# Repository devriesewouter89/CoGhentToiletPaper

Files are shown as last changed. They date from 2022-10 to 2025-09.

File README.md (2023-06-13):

# CoGhentToiletPaper

## Project

	Bringin heritage closer to the people.
An installation interpreting images from [Collectie van de Gentenaar](https://www.collectie.gent/).

The installation places images on a unique timeline, where each image is semantically connected one way or the other.

This timeline is then printed on toilet paper.

_That's about as close as it gets to the people._

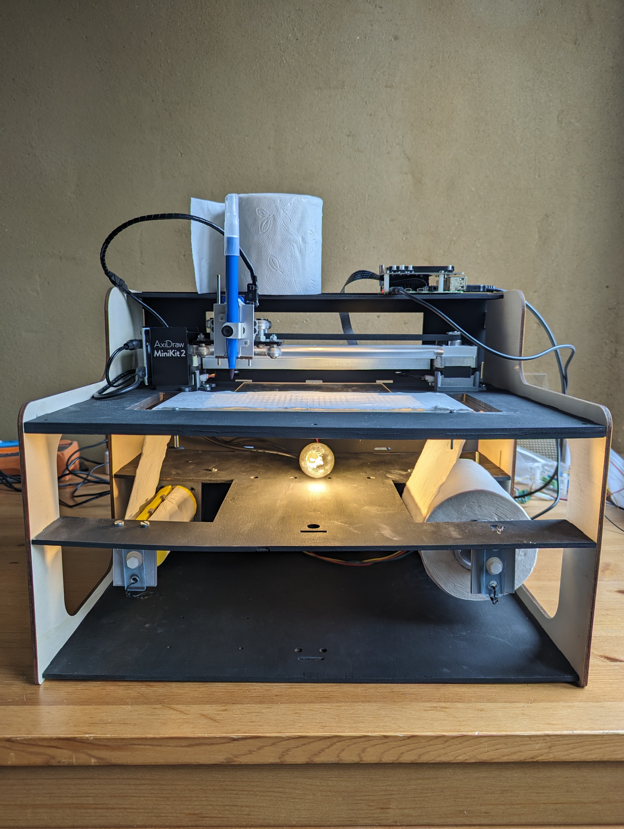
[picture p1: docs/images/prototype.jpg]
prototype


## installation

1. Start with a **64-bit** raspberry pi OS as Git lfs needs 64 bits

	tip: enable SSH & setup headless wifi via raspberry pi Imager and CTRL+SHIFT+X

2. Install GIT-lfs:
```bash
wget -c https://github.com/git-lfs/git-lfs/releases/download/v3.2.0/git-lfs-linux-arm64-v3.2.0.tar.gz -O - | tar -xvzf -
cd git-lfs-3.2.0
sudo ./install.sh
```

3. clone the repo with submodules and lfs:
```bash
git clone --recurse-submodules https://github.com/devriesewouter89/CoGhentToiletPaper/
cd CoGhentToiletPaper
git lfs pull
git submodule update --init --recursive
```

4. copy `.env.template` to `.env` and adapt to your needs.
5. install graphviz: `sudo apt install graphviz`
3. install poetry: `curl -sSL https://install.python-poetry.org | python3 -`
4. install all packages: `poetry install`
5. enable the environment: `poetry shell`

[//]: # TODO: adapt [prep_env.sh](./prep_env.sh)

[//]: # ()
[//]: # (**optional:** Want to run docker containers? install docker:)

[//]: # (```bash)

[//]: # (curl -fsSL https://get.docker.com -o get-docker.sh && sudo sh get-docker.sh)

[//]: # (sudo groupadd docker)

[//]: # (sudo usermod -aG docker ${USER})

[//]: # (sudo reboot)

[//]: # (```)

[//]: # ()
[//]: # ()
[//]: # ()
[//]: # ()
[//]: # (### image conversion)

[//]: # ()
[//]: # (multiple approaches:)

[//]: # (1. docker)

[//]: # (2. jupyter notebook)

[//]: # (3. directly via python scripts)

[//]: # ()
[//]: # ()
[//]: # (#### docker )

[//]: # ()
[//]: # (if CUDA cores available:)

[//]: # (```bash)

[//]: # (docker build -f Dockerfile.GPU -t imageconversion .)

[//]: # (```)

[//]: # ()
[//]: # (else )

[//]: # ()
[//]: # (```bash)

[//]: # (docker build -f Dockerfile.CPU -t imageconversion .)

[//]: # (```)

[//]: # ()
[//]: # (to run with the example folders: )

[//]: # (```bash)

[//]: # (docker run --name imgconv --mount type=bind,source="$&#40;pwd&#41;"/input,target=/coghent_input --mount type=bind,source="$&#40;pwd&#41;"/output/lineart,target=/workspace/coghent_vectors --mount type=bind,source="$&#40;pwd&#41;"/output/vectors,target=/workspace/coghent_lineart imageconversion)

[//]: # ()
[//]: # (```)

[//]: # ()
[//]: # (and then to start it:)

[//]: # (```bash)

[//]: # (docker start -a imgconv)

[//]: # (```)

## Nice to haves

### a web ui

perhaps in flutter? to check the state of the statemachine

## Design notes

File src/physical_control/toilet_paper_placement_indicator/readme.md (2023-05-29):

# template matching

    "hi chatgpt
    I need to align toilet paper based on the notches in the paper to two parallel lines. I want to use a camera and a machine learning model. Yet I don't know which kind of model to use, do you have a suggestion how to detect notches in paper?"
> "Hello! One approach you could take to detect the notches in the toilet paper using a camera and machine learning model is to use a computer vision technique called template matching. This involves creating a template image of a single notch and then using this template to search for instances of the notch in an input image. 
> 
> To create the template image, you can simply take a picture of a single notch using the camera. You will then need to pre-process the template image by converting it to grayscale and possibly applying some image filtering to improve the contrast and remove noise.
>
> To search for instances of the notch in the input image, you can use a technique called convolution to slide the template image over the input image and compare the template to each subregion of the input image. You can then use a metric to determine how closely the template matches the subregion, and if the match is above a certain threshold, you can consider the subregion to contain a notch.
> 
> There are many differing ways you could implement template matching, and the specific approach you take will depend on the specifics of your problem and the resources you have available. I hope this gives you a general idea of how you could approach this problem!"

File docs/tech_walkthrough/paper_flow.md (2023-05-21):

# paper flow

## steppers + camera

template matching
    => threshold + move away first before deciding to look again
need for light underneath paper to have enough contrast
work with region of interest: when does the paper leave or enter the region of interest?
    
needed to alter i2c address (by soldering a short circuit connection on pads)

## suction

fan beneath the paper
problem: turbulent air, not with prototype, yet with final version ==> no major issue

## angle 

I wanted a steep angle, for a certain visual appeal.
problem was that it tore the paper at the notches (it is intended for this of course...). So I had to make the angle less steep and make sure no sharp edges were in the path (smooth sanding to the rescue)

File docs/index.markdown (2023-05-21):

---
# Feel free to add content and custom Front Matter to this file.
# To modify the layout, see https://jekyllrb.com/docs/themes/#overriding-theme-defaults

layout: home
title: "Collectie van de Gentenaar: Gentse rol van het wc"
nav_order: 1
---

	Bringin heritage closer to the people.

An installation interpreting images from [Collectie van de Gentenaar](https://www.collectie.gent/){: .btn .btn-blue }.

The installation places images on a unique timeline, where each image is semantically connected one way or the other.

This timeline is then printed on toilet paper.

_That's about as close as it gets to the people._

prototype

## Oorsprong

*soon*

## Voortgang

*soon*

## walkthrough

Underneath [installation](./walkthrough/installation.html){: .btn } I've written an overview of the setup, from the
journey the toilet roll takes.

In [Software](./walkthrough/software.html){: .btn} there's a short writeup on all things software.

## Build it yourself

underneath [physical construct](https://github.com/devriesewouter89/CoGhentToiletPaper/tree/main/physical_construct) you
can find :

- the Fusion360 model (parameterized for plate thickness)
- lasercut files (plate thickness 3.8mm, create new lasercut files via the fusion360 model)
- the 3D print models

BOM:

- Raspberry Pi 4B
    - with power supply
    - with SC card
    - Raspberry pi Camera V3
- [Axidraw mini kit 2](https://shop.evilmadscientist.com/productsmenu/924)
- [Adafruit DC stepper hat](https://www.adafruit.com/product/4280)
- 2x Nema17 stepper
- bolts and nuts
- light bulb E14
- [light bulb fixation](https://www.gamma.be/nl/assortiment/profile-fitting-e14-zwart-2-st/p/B447774)
- [LCD Keypat hat](https://www.dfrobot.com/product-1884.html)
- large fan (to be defined)
- markers
    - I used children's markers, as they have a soft tip, useful for toilet paper and they don't dry out. Saves some
      headaches and running around.

# project origin

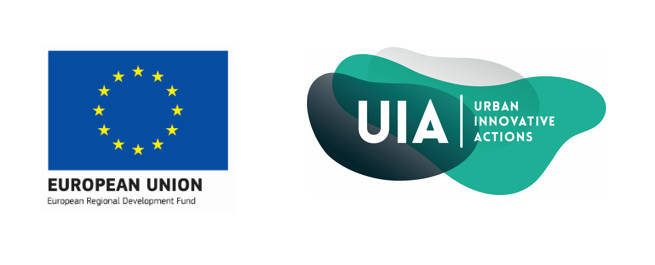
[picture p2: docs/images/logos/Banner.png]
UIA & europe

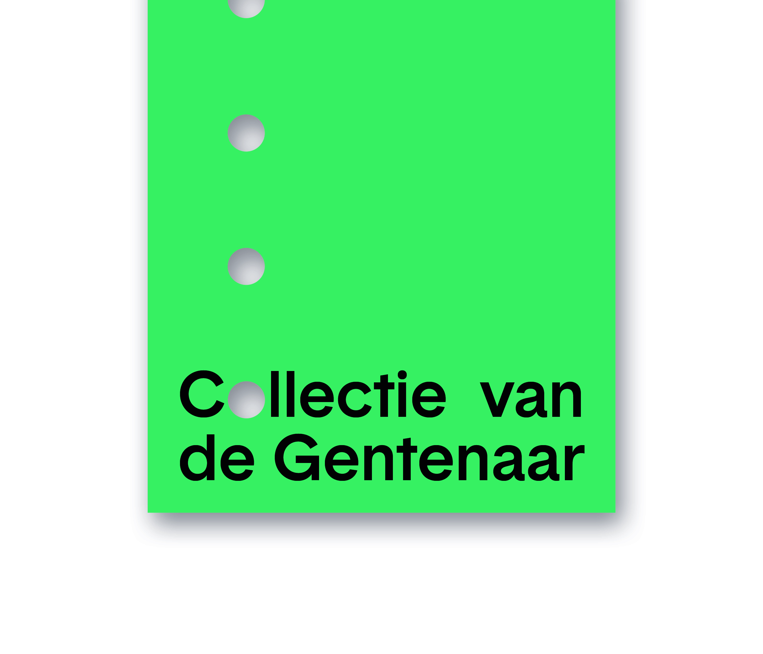
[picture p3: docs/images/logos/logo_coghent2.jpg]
coghent


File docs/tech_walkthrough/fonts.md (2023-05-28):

# fonts

going for the pen plotter with a wide soft tip, in combination with toilet paper, makes the ink flow too wide.

A couple of actions need to be taken into account:

## single line fonts

Most of the times we use outline fonts. Problem with plotters is that they draw the outlines, so they basically pass two times over the same region.
For a plotter it is best to have a single line font.

single vs outline fonts

[some more explanation](http://imajeenyus.com/computer/20150110_single_line_fonts/index.shtml)

## font size

## amount of text

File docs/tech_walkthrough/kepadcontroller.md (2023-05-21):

# keypad controller

manual intervention (to be programmed)
follow where in the flow we are

Needed to alter the i2c address of steppers as both were at same address.

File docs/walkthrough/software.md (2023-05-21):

---
# Feel free to add content and custom Front Matter to this file.
# To modify the layout, see https://jekyllrb.com/docs/themes/#overriding-theme-defaults

layout: page
title: "Software overview"
---

# Software overview

device level: Raspberry pi

language: Python

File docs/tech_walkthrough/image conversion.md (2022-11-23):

Target: prepare an image to be 2D plotted

Problem: images are mostly camera pictures, high res. Thus we need to convert it to line art to be able to plot it.

Found a cool repo: artline, If combined with some tracing programs, this was a good way to go to generate my lineart. Yet due to need of cuda to be able to run it, or need pytorch compiled for CPU. I had a rpi4 lying around, yet immediately getting pytorch (old version!) functioning gave problems with torchvision. I then started looking for some nvidia jetsons, yet apparantly covid chip shortage isn't over yet... So either I had to wait for some jetsons, or recompile pytorch, or go for another approach...

I found a different repo which did 

https://monokai.medium.com/how-to-wirelessly-plot-with-the-axidraw-f9e0a872138e

try with e.g. `saxi plot -s A5  --pen-down-height 2 --pen-up-height 25 --path-join-radius 1 0.svg`

PLOT with pencil what the borders are of A5, then measure the distance for the toilet paper ==> adapt svgs for this.

I've noticed the repo isn't up-to-date anymore and has some issues with polylines, therefore I've adapted my scripts to use only paths in svg.
Basically to avoid my lack of js and dependencies.

## Issues on the toilet paper front

1. paper moving
	1. test with multiple holed plates
	2. perhaps stronger suction? 
2. paper ripping with too many lines/ink
	1. lower the amount of lines close to each other?
3. placement of plotter vs paper 
	1. need to have a fixed position!
	2. have size fixed in 'saxi' library
4. pen vs pencil?
	1. test setup
5. which kind of toilet paper?

## platform

### 3D printed parts

#### fixation for toilet paper
- remove collar
- 2nd part: have fixed size and smaller stem coming out to center
- hole for stepper to big & not aligning nicely
- have at the beginning also some support for rolling?
#### fixation for roll rollers
2x https://www.thingiverse.com/thing:18019
or 2x https://www.thingiverse.com/thing:990946

#### fixation for axi draw
https://www.thingiverse.com/thing:669325 ==> adapt
1x with extraneous holes for screwing
1x half this design, with extraneous holes

#### connection for suction? 
kruimeldief

### platform
#### fixations for rollers & axi draw
- next to each other
- have not holes, but lines, to be able to align the axi draw & rollers slightly
#### colored line
have a not so comon colour to detect?
Or better black, but have image clear of other black things
#### suction panels
3 layer:
1. top layer: multiple hole configurations
2. middle layer: open surface to spread oxygen
3. bottom layer: access for suction pipe
glue middle and bottom
engrave or route the top and middle one to remove some material. in there we place some rubber or let dry some tec7 (separately) to remove air gaps
#### fixation for camera

#### placement of components:
- axidraw **above** the platform
- rollers **beneath** the platform
- camera **above** the platform
raise the platform approx 15cm, keep it tight not to have wiggle when printing

ME311549

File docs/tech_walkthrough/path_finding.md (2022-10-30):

Idee was startpunt te kiezen, sprong in de tijd maken en een zekere rang behouden. In die range kijken of er matches zijn.

Probleem 1: datums in de stream stonden niet mooi en met vreemde karakters ==> dit opkuisen
```python
def convert_column_first_year_via_regex(self):  
    """  
    convert_column_first_year_via_regex is a function that formats the "converted_creation_date" column in the pd dataframe to something readable    
    """    
    res = self.df[self.time_col].str.extract(r"([\d+]{4})").squeeze()  
    self.df.insert(10, self.clean_time_col, pd.to_numeric(res), True)
```

Eerste naieve testcase: ervan uitgaan dat er voldoende data is en kijken of ik, met voldoende tussenstappen (= # wc rol velletjes) voldoende afbeeldingen vind op x afstand en met een link tussen elkaar.

- Hoe de link zoeken? Lemmatization vs stemming van geselecteerde kolommen

%%todo: zet tekening van voorbeeld erbij (print statement)%%
x afstand: eerst op basis van tijd. Wat bleek: data niet uniform genoeg verspreid en tijd lijkt moeilijke metric.
Oplossing: laat tijd los! sorteren van alle entries op basis van tijd, maar dan gewoon sprong maken in de lijst met iedere keer een specifieke afstand en range. Dit komt ongeveer overeen met rekening te houden met de tijdsdistributie en toch te denken in tijd, maar veel gemakkelijker te implementeren.

van

```python
def find_indices_in_time_range(self, origin_year: int, time_distance: int, time_spread: int) -> (bool, list[int]):  
    new_origin = origin_year + time_distance  
    new_time_range = [new_origin - time_spread,  
                      new_origin + time_spread]  
    bool_array = self.df.index[  
        (new_time_range[0] <= self.df[self.clean_time_col]) & (self.df[self.clean_time_col] <= new_time_range[1])]  
    if len(bool_array) > 0:  
        res = bool_array.values.tolist()  
        res_bool = True  
    else:  
        res = None  
        res_bool = False  
    return res_bool, res
```
waar we in tijdstappen dachten naar:
```python
def 
```

Nu hebben we een forward motion die rekening houdt met de distributie ifv de tijd, om een path te vinden moeten we een boomstructuur aanmaken, want het is niet gezegd dat we altijd connecties gaan vinden en af en toe moeten we een tak verlaten en een andere tak uitproberen om tot op het einde te geraken! ==> backward motion

Afbeeldingen: de link downloaden: blijkt bij relatief wat afbeeldingen krijg ik geen afbeelding?

```python 
def get_image_uri(self, img_id) -> str:  
    iiif_manifest = "https://api.collectie.gent/iiif/presentation/v2/manifest/{}:{}".format(self.institute, img_id)  
    try:  
        response = urlopen(iiif_manifest)  
    except ValueError:  
        print('no image found')  
    except HTTPError:  
        print('no image found')  
    else:  
        data_json = json.loads(response.read())  
        image_uri = data_json["sequences"][0]['canvases'][0]["images"][0]["resource"]["@id"]  
        return image_uri
def get_image_list_from_tree(self):  
    # we pick the rows from our dataframe which were chose  
    index_list = self.df_tree[self.df_tree["chosen"] == True].index  
    # based on these indexes we pick the data from within our original dataframe  
    df_list = self.df.iloc[self.df.index.isin(index_list)]  
    # we make a list of the objectnumbers, as they are needed to retrieve images  
    object_id_list = df_list["objectnumber"].values  
    img_list = list(map(lambda x: self.get_image_uri(x), object_id_list))  
    for i in img_list:  
        print(i)  
    print(len(img_list))
```
Got me on a random occasion only 12 out of 50 results. Not good...

Plan van aanpak: bij het bouwen van de tree reeds rekening houden met het resultaat van get_image_uri!

Nu wordt alles wel heel traag (serieel alle uri's opvragen), dus gaan we threaded werken!

Van 
```python
def find_overlap_in_series(self, origin, indexes) -> (bool, list[dict]):  
    """  
    @rtype: object  
    @param origin:    @param indexes:    """  
    print("origin:")  
    print(self.df_row(origin))  
    res = list()  
    res_found = False  
  
    for i in indexes:  
        if i == origin:  
            continue  
        # print(self.df_row(i))  
        overlap_found, overlap_list, img_uri = self.find_overlap(origin, i)  
        if overlap_found:  
            print(Fore.GREEN)  
            print(overlap_list)  
            res.append({"index": i, "res": overlap_list, "img_uri": img_uri})  
            res_found = True  
        else:  
            # print(Fore.RED + "nothing found")  
            continue  
        print(Style.RESET_ALL)  
    return res_found, res
```

Naar threaded:

```python

def find_overlap_threaded_in_series(self, origin, indexes) -> (bool, list[dict], list[str]):  
    """  
    TODO not satisfied with this, not functionally written!  
    @rtype: object  
    @param origin: the index in the original dataframe for which we're looking for childs in <indexes> with a textual overlap    @param indexes: the indexes of possible children    """  
    print("origin:")  
    print(self.df_row(origin))  
    res = list()  
    res_found = False  
  
    # we'll multithread the find_overlap function to speed things up  
    que = Queue()  
    threads_list = list()  
    for i in indexes:  
        if i == origin:  
            continue  
        t = Thread(target=lambda q, arg1, arg2: q.put(self.find_overlap(arg1, arg2)), args=(que, origin, i))  
        t.start()  
        threads_list.append(t)  
    for t in threads_list:  
        t.join()  
    while not que.empty():  
        overlap_found, overlap_list, img_uri, index = que.get()  
        if overlap_found:  
            print(Fore.GREEN)  
            print(overlap_list)  
            res.append({"index": index, "res": overlap_list, "img_uri": img_uri})  
            res_found = True  
        else:  
            # print(Fore.RED + "nothing found")  
            continue  
        print(Style.RESET_ALL)  
    return res_found, res
```

Now, my algorithm is basically:
- You have a startnode
- Find all indices we want to evaluate
- Find all childs based on the indices which have a textual overlap with our startnode
- choose one of them as a new startnode
	- If no child nodes are to be found, switch the new startnode

As this takes a long time, perhaps it's faster for future reference to NOT choose the new startnode, yet search childs with overlaps for all nested childs. This implicates:
- more memory usage
- small rewriting part (not choosing one branch + keeping track of the parent)
- if the database is renewed, entire process needs to be redone.

So I've rewritten my flow for easier reuse:
- instead of finding a unique path and only saving this path towards the end
- I build the entire tree structure
- and find a possible path afterwards
- This way making it possible to recuperate the builded tree structure.
As I only keep a link to the images, I don't have this huge memory bounty.

Now, after having some hassles rewriting the code in threads. It takes a **long** time to make the tree structure. That made me think that I check often for the same entry if there's an image present as they appear in different branches. Thus, I'll rewrite the code again to add the uri, if available, to the original dataframe. Then I don't need to have so many requests (which is the bottleneck, together with my sense of patience)

I now preprocess the data to first go through all images and find their URI, if there's none I don't keep them. 
My initial plan was to process all data into a tree, yet after running an entire night I came to next conclusion: it's becoming way to large and slow. I need 50 layers, by morning I had 9 (with 1000 threads in parallel, and a spread of 3):

- layer 1: 1 id to check @ 22:25:34
- layer 2: 5 ids to check
- layer 3: 30 ids to check
- layer 4: 150 ids to check
- layer 5: 738 ids to check
- layer 6: 3947
- layer 7: 19849
- layer 8: 94446
- layer 9: 444545  (400000 @ 08:35:35) ==> I'm not that patient!

each 1000 threads took approx 2 minutes at layer 9. Perhaps my dataframe is becoming too large to be efficient... At layer 8 it was about 20 seconds...

So I went for again a different approach:
- first check for each entry if there's an image present as well as a useful date. Other entries I drop.
	- Especially the image present gave a huge dropout:
		- for dmg: out of 9142 ids, we got next HTTP errors: {'403': 1245, '404': 6789, '502': 18}
		- in DMG there are some weird object ids: `/iiif/presentation/v2/manifest/dmg:DES. 1995.16_0-2` what's the space doing there? the object can't be found + throws an error 
		- for hva: `of 8574 ids, we got next HTTP errors: {'403': 9, '404': 6700, '502': 2}`

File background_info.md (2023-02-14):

[pen plotters](https://uunatek.com/top-5-best-axidraw-xy-plotter-pen-plotter-alternatives/)

[print on masking tape](https://hackaday.com/2022/05/09/all-the-sticky-labels-you-could-ever-need-no-drm-just-masking-tape/)

[evil mad scientist plotter](https://shop.evilmadscientist.com/)

[AI model art to line art](https://github.com/vijishmadhavan/ArtLine)

blob detection voor grote zwarte vlakken
contour blob behouden, opvullen ahv hatch

https://learnopencv.com/blob-detection-using-opencv-python-c/ ?
https://ezdxf.readthedocs.io/en/stable/tutorials/hatch.html ?

[potrace](https://pypi.org/project/pypotrace/) ==> of im2vec of deepSVG

[DIY pen plotter with automatic tool changer](https://www.youtube.com/watch?v=virDtVVt2Xo)

[diy plen plotter](https://www.youtube.com/watch?v=u26Wt8eY5zc)

[cheap chinese woodworking tools reviewed](https://www.hookedonwood.online/China-Tools/)

[docker+nvidia+vscode development](https://blog.roboflow.com/nvidia-docker-vscode-pytorch/)

[IIIF tricks](https://iiif.io/api/image/3.0/)
e.g. rescale images: https://github.com/CoGhent/random_image_viewer/blob/master/getimage/views.py line 45

To align toilet paper, should I be using segmentation masks?
https://blog.roboflow.com/how-to-create-segmentation-masks-with-roboflow/

# rpi camera mount

- https://www.thingiverse.com/thing:3079477 ?

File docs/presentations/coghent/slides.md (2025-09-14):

---
theme: apple-basic
class: text-center
highlighter: shiki
lineNumbers: false
info: |
  Presentation slides for Collectie van de Gentenaar

drawings:
  persist: false
layout: intro
title: Gentse Rol van het WC
---

# De Gentse rol van het WC

Wouter Devriese

---
transition: fade-out
---

# Oorsprong

1. collectie - LDES:
    1. weerspiegeling fysieke collectie
    2. semantisch verrijkt
    3. definitieve inhoud? (updates - toevoegingen)

<v-click>

2. hoe kan men naar de collectie kijken?
    1. minder gecureerd
    2. individu kiest zelf pad doorheen de collectie
    3. persoonlijk: muziek leren kennen
        1. voor gekauwde playlists 
        2. zelf verbanden zoeken

</v-click>

<!--
het punt van de collectie is dat het dus op een LDES stream staat, wat ik daar persoonlijk uit interessant vond was het punt dat het naast de weerspiegeling van de fysieke collecties, ook semantisch verrijkt is, en dat objecten updates kunnen krijgen, of dat objecten toegevoegd worden. De collectie krijgt zo een dynamisch kantje

-->

---
layout: default
transition: fade-out

---

# Brainstorm 

Algemene vragen:

- tijdslijn?
- fysiek aandenken?
- collectie tot bij burger?

...

---
layout: image-right
image: https://i.guim.co.uk/img/media/e1492f95308c7f3b1c1e13ba51f57e02fd4021c5/0_236_7087_4254/master/7087.jpg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
---

# Brainstorm 

Algemene vragen:

- tijdslijn?
- fysiek aandenken?
- collectie tot bij burger?

...

WC-papier 

---
layout: image-right
image: ./images/prototype_2.jpg
---

# Installatie

- die telkens nieuwe paden doorheen de collectie zoekt
- deze print op een WC-rol
- zo unieke wc-rollen creerend

---
layout: 3-images
imageLeft: ./images/process/tree.png
imageTopRight: ./images/process/in_between.svg
imageBottomRight: './images/process/0.jpg'
---
---
layout: image-right
image: ./images/process/0.jpg
---

# download image

---
layout: image-right
image: ./images/process/lineart.png
layout: image-left
image: ./images/process/tree.png
---

# pad

"Deze **stoel** heeft een hoge rechte rugleuning die wordt benadrukt door het snijwerk van de kapregel. 
De rechte achterpoten van de **stoel** lopen zonder onderbreking over in de stijlen van de rugleuning. 
Deze **stoel** werd geconstrueerd in de 19de eeuw met <u>vermoedelijk</u> <...>"

"Deze pronkzetel met vernieuwde <...> 
Achteraan steunt de **stoel** op sabelpoten ('à l'étrusque'). <...> werd hij <u>vermoedelijk</u> uitgevoerd in het midden van de 19de eeuw. 
Vergelijkbare **stoel**en zijn te vinden in de collecties van het Bayerisches Nationalmuseum in München en Musée des Arts Décoratifs in Parijs."

*'stoel', 'eeuw', 'vermoedelijk', '19de'*

---
layout: default

---


---

# convert to lineart
---
layout: image-right
image: ./images/process/0.svg
---

# convert to lineart
layout: default
image: 
---

# conversion



<!--

---
layout: image-right
image: ./images/coghent_fest.MP4
---

# Doel

*Erfgoed dichter bij de burger brengen*

nut van

<v-clicks>

- WC-rol als functioneel object 
    - niet noemenswaardig
- WC-rol als esthethisch object 
    - niet noemenswaardig
- WC rol & installatie als conversation starter

</v-clicks>
 -->
---
layout: image-right
image: ./images/fusion.jpg
---

# bouwen

<v-click>

- LDES als nieuwe technologie
- code
- mechanisch ontwerp:
    - fast prototyping (zaag + vijs + ducttape)
    - 3D print
    - lasercut
- open-source reproduceerbaar 
- WC-papier als medium = horror
</v-click>

---
layout: 3-images
imageLeft: images/paper/lots.jpg
imageTopRight: images/paper/notches.png
imageBottomRight: images/paper/too_much_ink.jpg
---

---
layout: default
transition: fade-out
---

# evolutie


---
layout: default
transition: fade-out

---

# evolutie

---
layout: default
transition: fade-out

---

# evolutie

---
layout: default
transition: fade-out

---

# evolutie

---
layout: default
transition: fade-out

---

# evolutie  
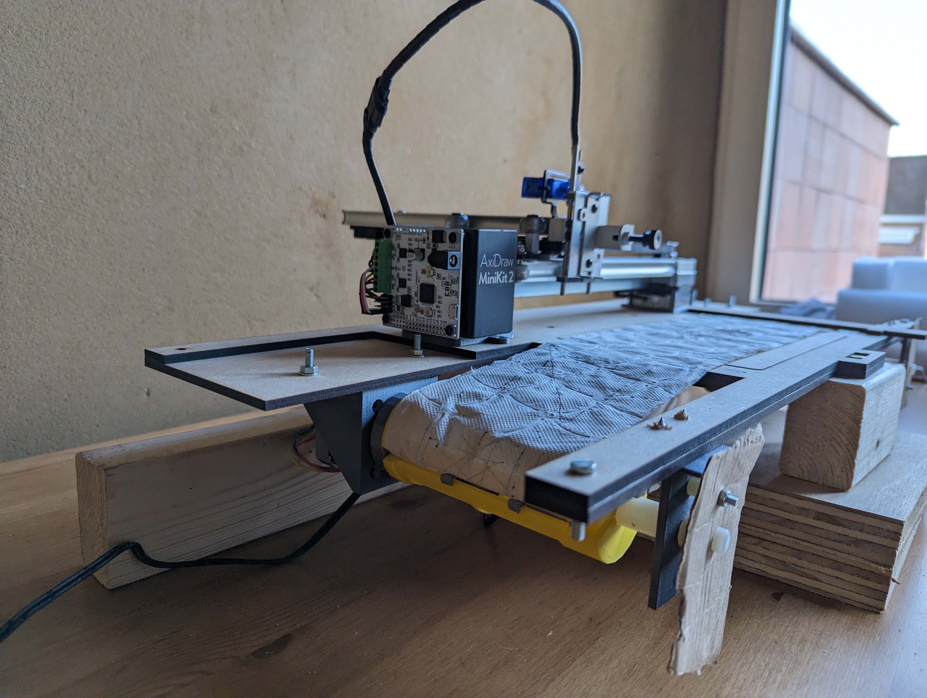
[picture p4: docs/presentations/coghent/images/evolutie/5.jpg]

---
layout: default
transition: fade-out

---

# evolutie

---
layout: default
transition: fade-out

---

# evolutie

---
layout: default
transition: fade-out

---

# evolutie

---
layout: default
transition: fade-out
---

# evolutie


---
layout: center
transition: fade-out
---

# "Final"
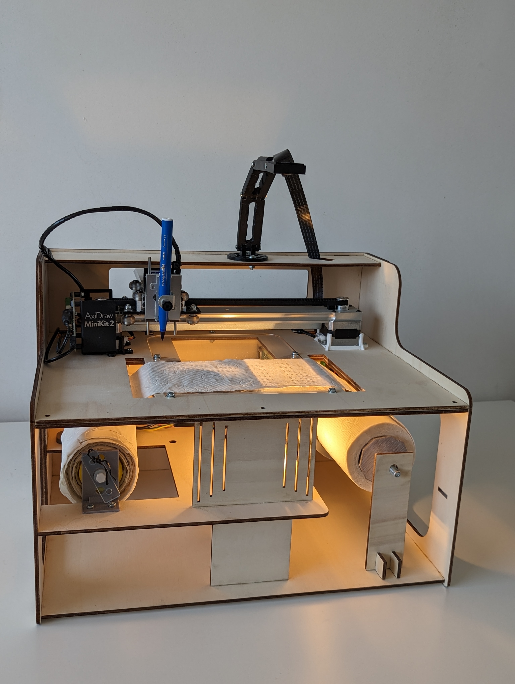
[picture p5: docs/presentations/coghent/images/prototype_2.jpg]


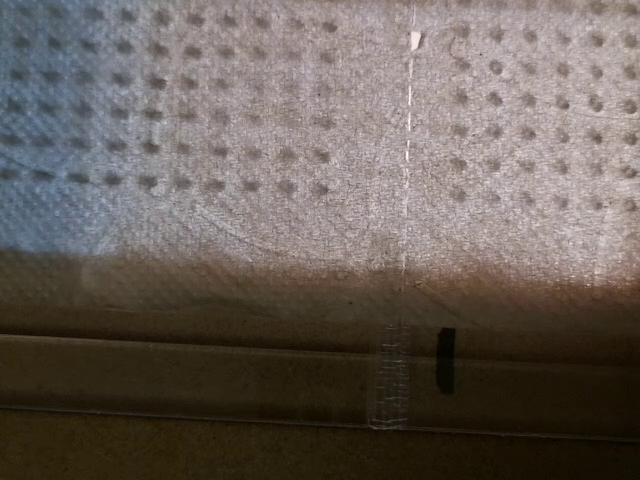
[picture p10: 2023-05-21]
docs/presentations/coghent/public/images/paper/notches.png

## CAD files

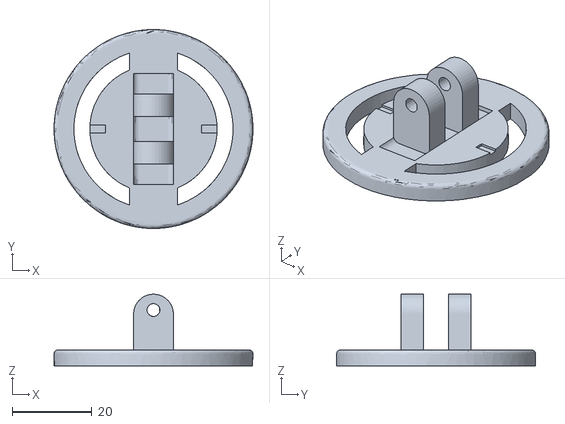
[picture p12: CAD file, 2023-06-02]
3DPrint/Camera/Camera_foot.stl
50.0 x 49.9 x 18.0

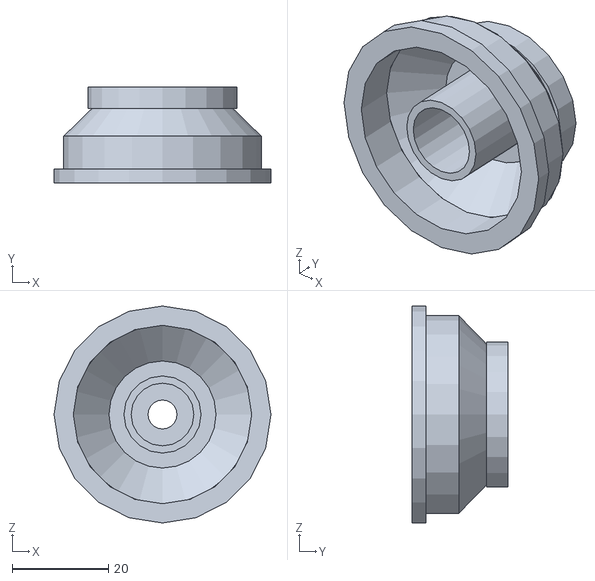
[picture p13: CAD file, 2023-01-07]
3DPrint/roll_fixation/paper_roll_side/other_side_toilet_fixation.stl
45.0 x 20.0 x 45.0

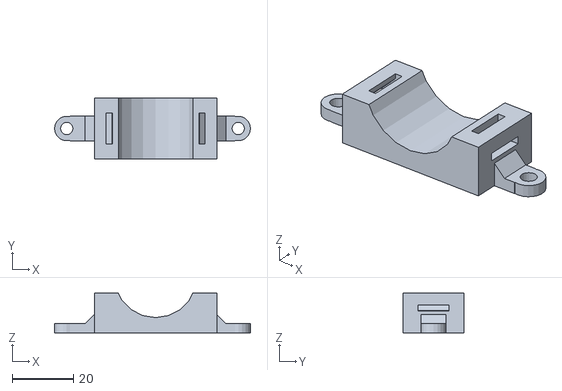
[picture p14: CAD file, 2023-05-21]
physical_construct/3DPrint/light_bulb_fixation.stl
64.0 x 20.0 x 13.0

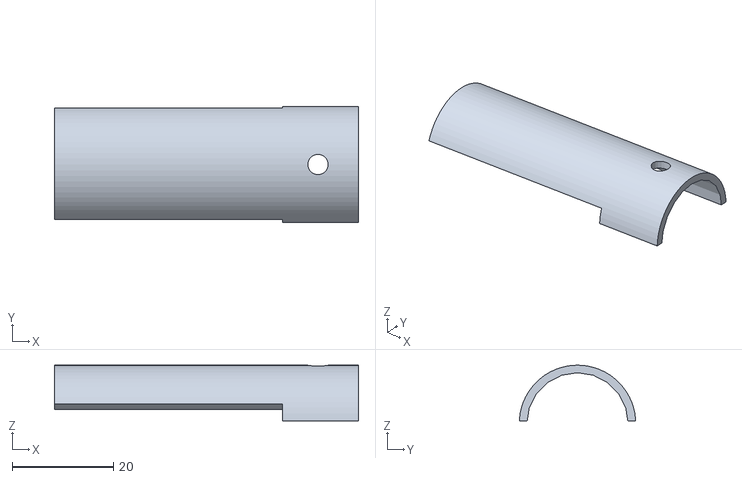
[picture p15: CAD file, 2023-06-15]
physical_construct/3DPrint/roll_fixation/grabber_side/v6_fix.stl
60.0 x 23.0 x 11.0

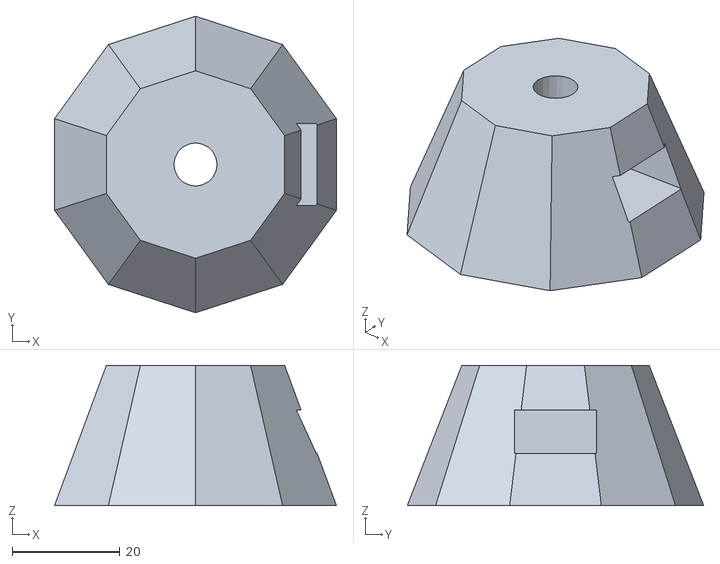
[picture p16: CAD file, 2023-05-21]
physical_construct/3DPrint/roll_fixation/paper_roll_side/roll_fixer.stl
52.3 x 55.0 x 26.0

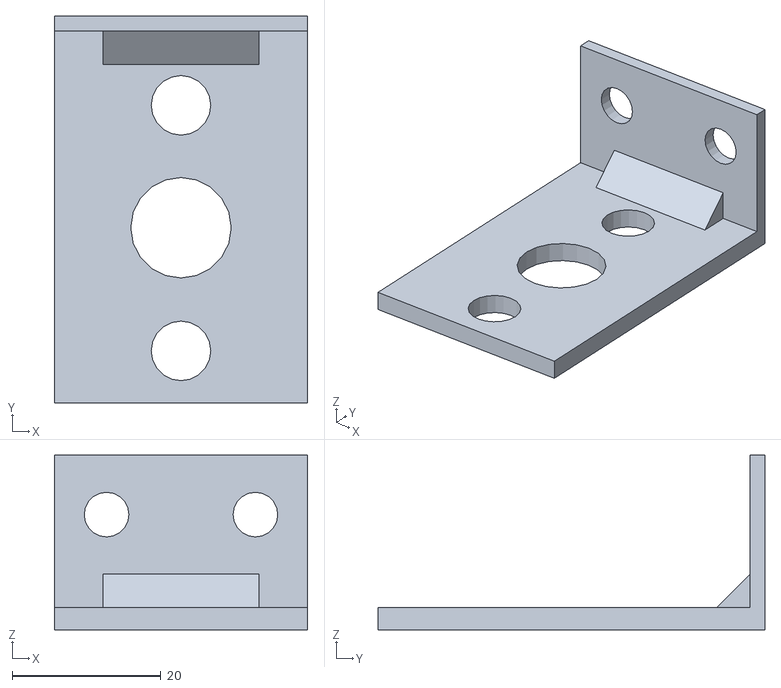
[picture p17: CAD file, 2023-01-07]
physical_construct/3DPrint/roll_fixation/toilet_roll_balancer.stl
34.0 x 52.0 x 23.5

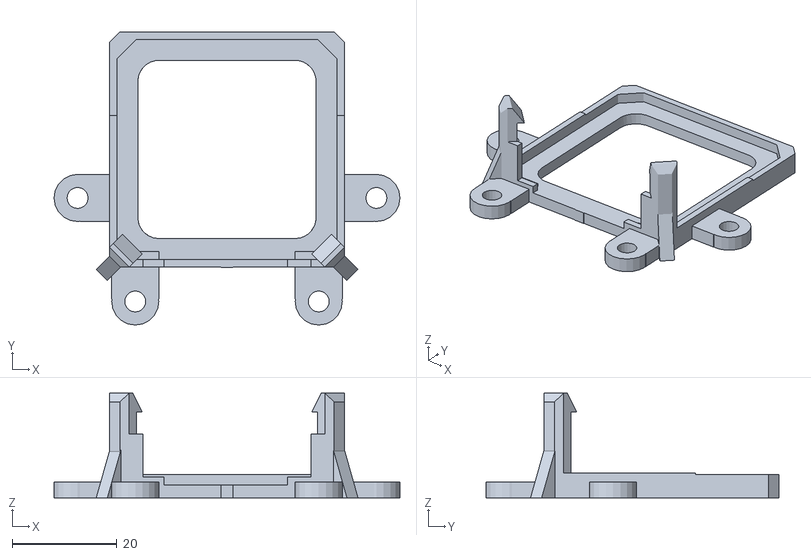
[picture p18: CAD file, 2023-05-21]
physical_construct/3DPrint/steppers/axi_draw_fixation/left_axi.stl
66.0 x 55.9 x 20.0

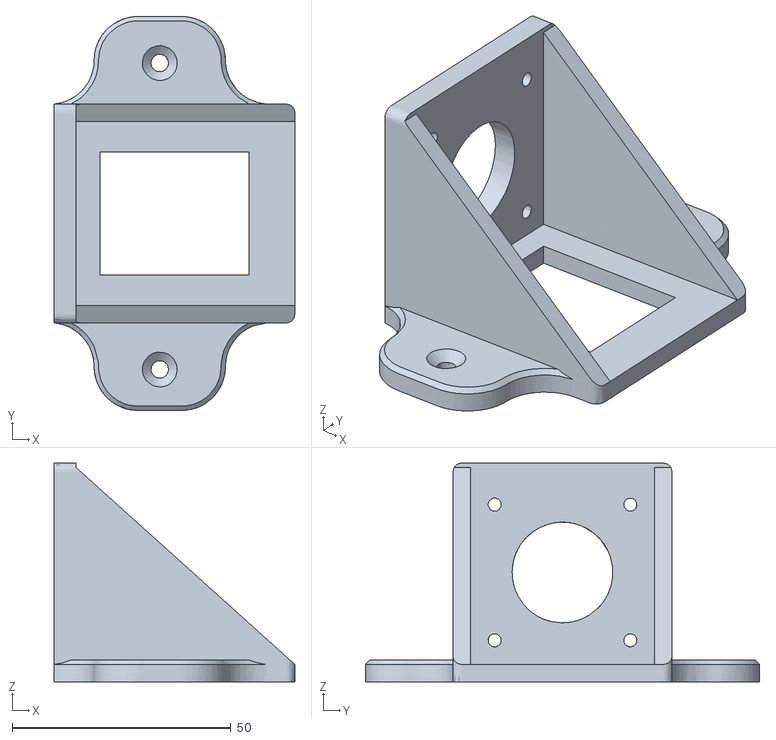
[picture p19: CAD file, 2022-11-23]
physical_construct/3DPrint/steppers/toilet_rollers/roller.stl
55.0 x 90.0 x 50.0

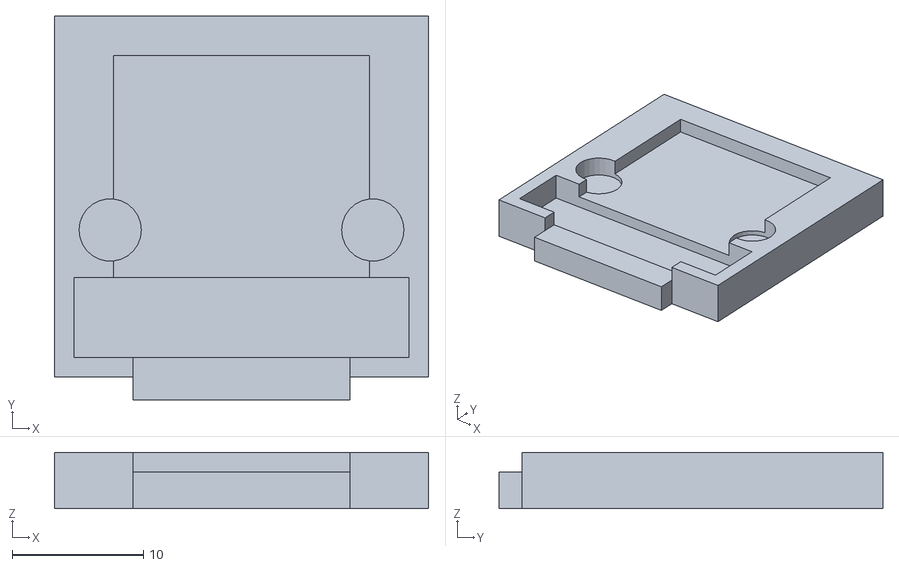
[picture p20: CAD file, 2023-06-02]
3DPrint/Camera/Camera_backplate.stl
28.5 x 29.2 x 4.30

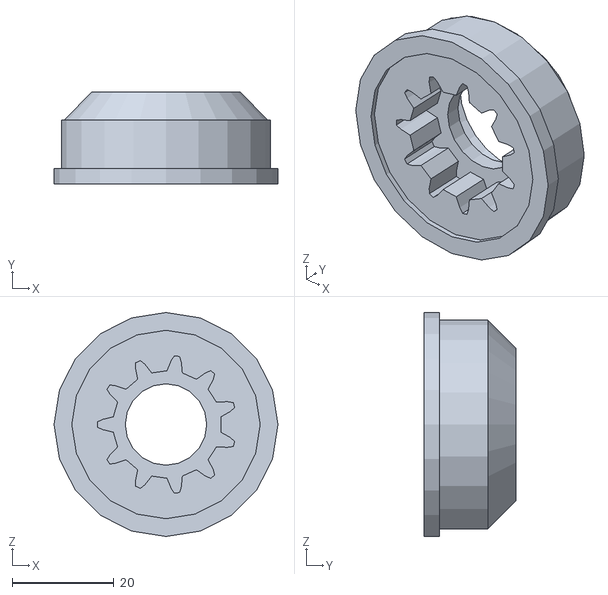
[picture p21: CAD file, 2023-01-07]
3DPrint/roll_fixation/paper_roll_side/nema17_toilet_fixation_1.stl
44.0 x 18.0 x 44.0

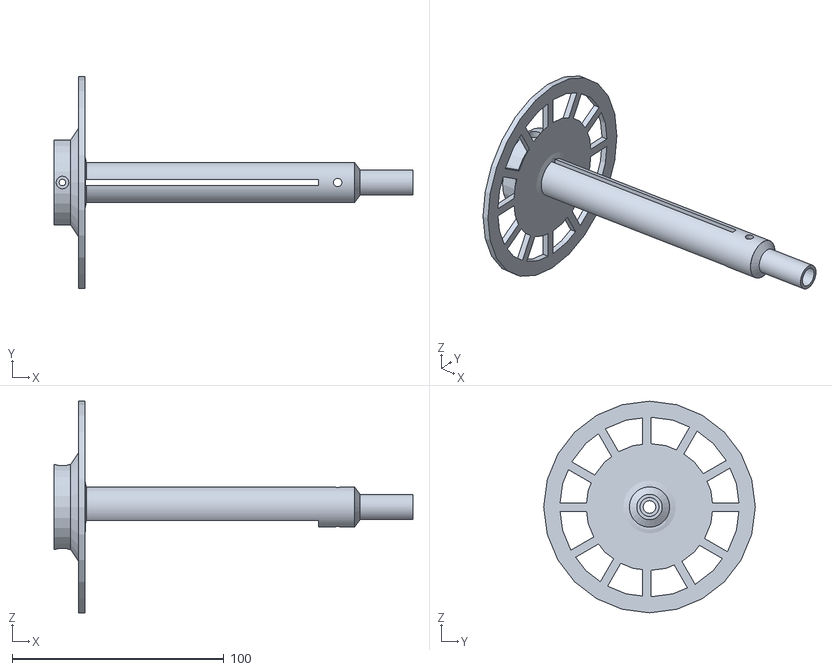
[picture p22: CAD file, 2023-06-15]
physical_construct/3DPrint/roll_fixation/grabber_side/v6.stl
169.6 x 100.0 x 100.0

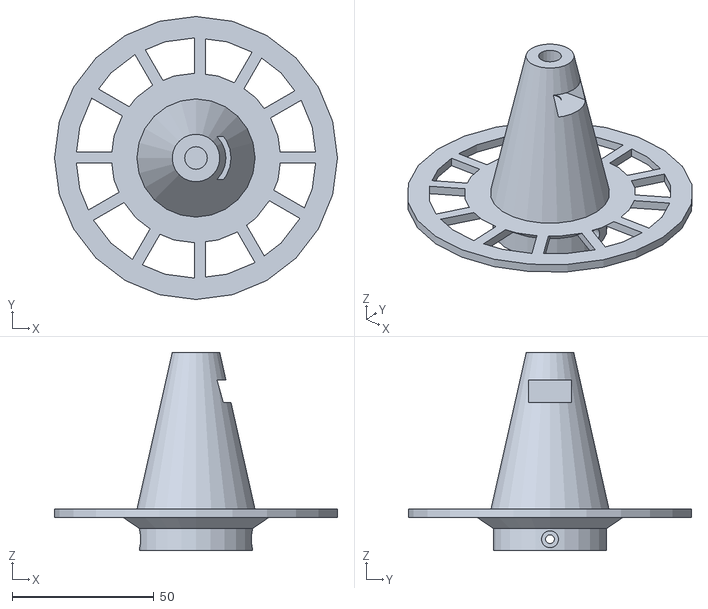
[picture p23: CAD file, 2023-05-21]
physical_construct/3DPrint/roll_fixation/paper_roll_side/roll_to_stepper.stl
100.0 x 100.0 x 70.0

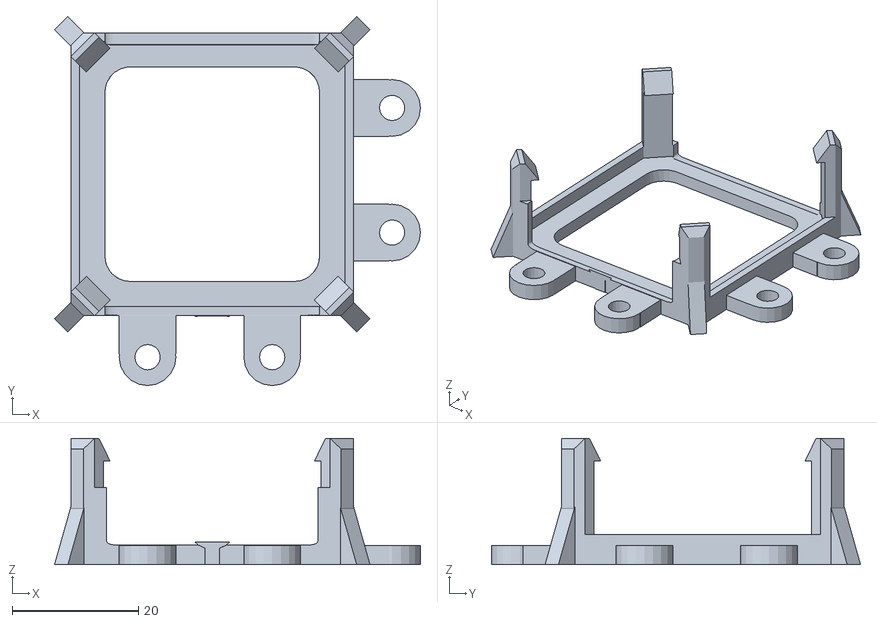
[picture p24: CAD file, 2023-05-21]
physical_construct/3DPrint/steppers/axi_draw_fixation/right_axi.stl
58.0 x 58.5 x 20.0

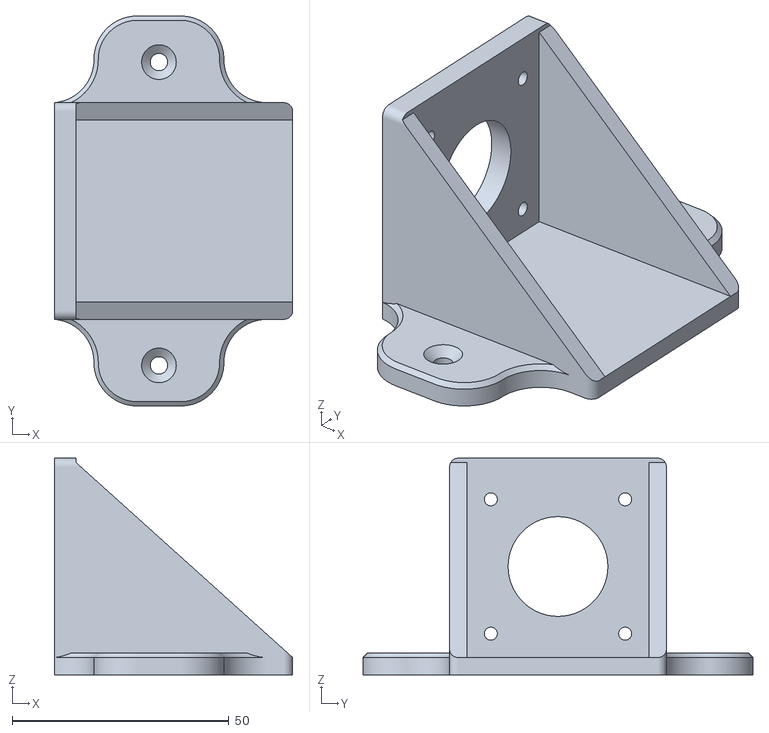
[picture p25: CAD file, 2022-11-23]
physical_construct/3DPrint/steppers/toilet_rollers/StepperMotorBracket.stl
55.0 x 90.0 x 50.0

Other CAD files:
3DPrint/Camera/Arm_3.stl
3DPrint/roll_fixation/paper_roll_side/nema17_toilet_fixation_2.stl
physical_construct/3DPrint/roll_fixation/grabber_side/toilet_grabber_insert_small.stl
3DPrint/Camera/Arm_1.stl
3DPrint/Camera/Arm_2.stl
3DPrint/Camera/Camera_frontplate.stl
physical_construct/3DPrint/roll_fixation/grabber_side/toilet_grabber.stl
physical_construct/3DPrint/roll_fixation/grabber_side/toilet_grabber_insert.stl
physical_construct/3DPrint/roll_fixation/paper_roll_side/OLD/nema17_toilet_fixation_2.stl

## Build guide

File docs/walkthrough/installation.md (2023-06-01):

---
# Feel free to add content and custom Front Matter to this file.
# To modify the layout, see https://jekyllrb.com/docs/themes/#overriding-theme-defaults

layout: page
title: "Installation Overview"
---

# Process

1. [getting the data and preparing it](#getting-the-data-and-preparing-it)
2. [insert paper roll](#insert-paper-roll)
3. [paper gets sucked down with the fan](#paper-gets-sucked-down-with-the-fan)
4. [two steppers to roll off the paper](#two-steppers-to-roll-off-the-paper)
5. [when to stop rolling? Camera + notches + light to the rescue](#when-to-stop-rolling)
6. [drawing via axidraw mini](#drawing-via-axidraw-mini)
7. [drawing with markers on toilet paper: the good, the bad & a lot of uglyness](#drawing--markers--toilet-paper)
8. [the physical setup: lasercut + 3D print](#the-physical-setup)

## Getting the data and preparing it

- initial plan: Nvidia Jetson, yet shortage, had an RPi 4 around.

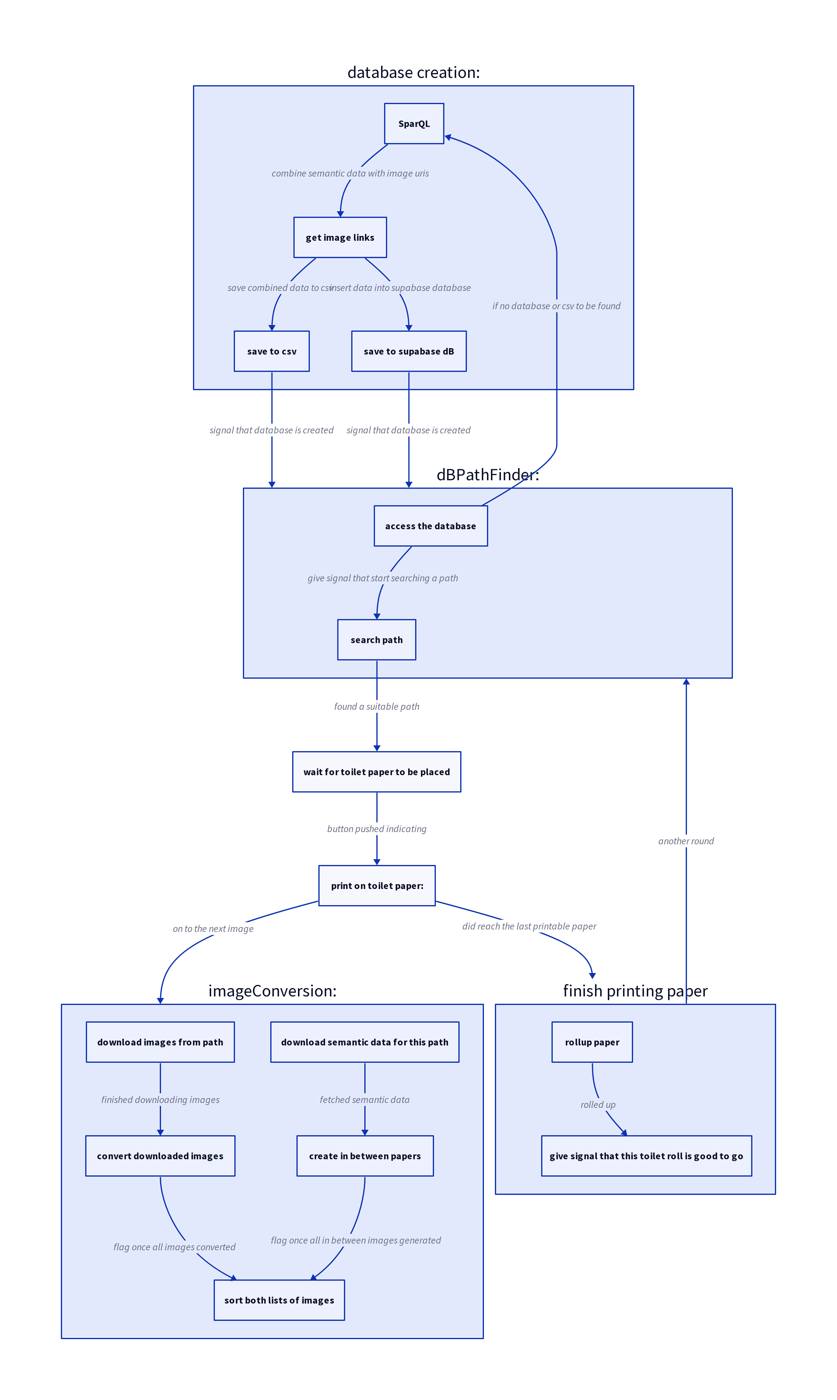
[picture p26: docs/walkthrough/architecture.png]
architecture overview


## insert paper roll

## paper gets sucked down with the fan

## two steppers to roll off the paper

- notice: had to sand of all hard corners & align the height of all different parts, so the corner the paper took was not too steep. otherwise the paper would get torn apart.

## When to stop rolling?

## Drawing via Axidraw Mini

## drawing + markers +  toilet paper

- fonts: single line fonts necessary
- ink flows: need to take into account not using small text
- markers: need soft tips (not tearing the paper) + 

## the physical setup

## raspberry pi hotspot when no wifi detected

https://www.raspberryconnect.com/projects/65-raspberrypi-hotspot-accesspoints/157-raspberry-pi-auto-wifi-hotspot-switch-internet

Notice: we can't use a virtual environment due to some used libraries. (#todo list which libraries)

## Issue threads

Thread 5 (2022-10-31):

3D model: fixation toilet paper on stepper motor

devriesewouter89, 2022-10-31:

Closed 2023-03-09.

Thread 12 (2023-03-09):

suction plate

devriesewouter89, 2023-03-09:
the pattern now looks too much like the pattern in paper, change it

Closed 2023-04-05.

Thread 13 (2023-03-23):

enclosure fixes

devriesewouter89, 2023-03-23:
- [x] gat ontbreekt voor middle high
- [x] logo's langs verkeerde kant
- [x] op middle high bevestiging voor camera of rechts van original roll?
- [x] gaten voor plotter komen niet overeen
- [x] ander houtdikte: hoe scalet alles?
- [x] hoogte van achterkant: moet cutout komen voor plotterarm
- [x] middle high breder om direct licht wat te blokken
- [x] alles moet dieper, wc papier geraakt er nu niet in...
- [x] afstand tandwielen moet dieper zitten om wc rol erop te kunnen zetten
- [x] plotter klein beetje naar rechts want anders kabeltje gekneld
- [x] gluif + glijder met verschillende afstandhouders voor rol ipv balancer

Closed 2023-03-27.

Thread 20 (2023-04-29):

stacking of ventilators?

devriesewouter89, 2023-04-29:
and try to reposition them underneath the holes? turbulent air gives problems right now

devriesewouter89, 2023-05-27:
solved by having some spacing between fan and plexi

Closed 2023-05-27.

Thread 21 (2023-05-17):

presentatie

devriesewouter89, 2023-05-17:
hoe linked data geleveraged
wat is het voordeel aan de linked data
conceptuele
welke moeilijkheden
reflecties over LDES: moet mijn data per se up to date zijn?

7 min 15.00-16.00h balzaal vrijdag

Closed 2023-06-13.

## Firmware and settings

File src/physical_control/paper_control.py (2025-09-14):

"""Simple test for using adafruit_motorkit with a stepper motor"""
import argparse
import sys
import time
from pathlib import Path

import board
import git
from adafruit_motor import stepper
from adafruit_motorkit import MotorKit
from sshkeyboard import listen_keyboard

from src.config_toilet import Config
from src.physical_control.toilet_paper_placement_indicator.template_matching import CamControl, SheetPlacement, PLACEMENT


def get_project_root():
    return Path(git.Repo('.', search_parent_directories=True).working_tree_dir)


try:
    sys.path.index(str(get_project_root().resolve()))  # Or os.getcwd() for this directory
except ValueError:
    sys.path.append(str(get_project_root().resolve()))  # Or os.getcwd() for this directory


class StepperControl:
    def __init__(self, config: Config):
        """
        """
        self.kit = MotorKit(i2c=board.I2C(), address=config.stepperi2c) #todo
        self.total_roll = 0
        self.placement = PLACEMENT.NOT_FAR
        self.config = config
        self.cc = CamControl(config)
        self.sheet = SheetPlacement(self.cc, config)

    def test_stepper(self):
        for _ in range(10):
            for _ in range(100):
                self.kit.stepper1.onestep(direction=stepper.FORWARD, style=stepper.SINGLE)
                self.kit.stepper2.onestep(direction=stepper.BACKWARD, style=stepper.SINGLE)
            time.sleep(1.0)
            for _ in range(100):
                self.kit.stepper1.onestep(direction=stepper.BACKWARD, style=stepper.SINGLE)
                self.kit.stepper2.onestep(direction=stepper.FORWARD, style=stepper.SINGLE)
            time.sleep(1.0)
        self.kit.stepper1.release()
        self.kit.stepper2.release()

    def calibrate_template_matching(self):
        self.sheet.prepare()

    def move_paper_right(self, amount_of_steps: int = 50):
        """
        for some reason, I need to direct both steppers in order to be able to pull back the paper
        @param amount_of_steps:
        @return:
        """
        self.total_roll -= amount_of_steps
        self.kit.stepper1.release()
        for _ in range(amount_of_steps):
           #self.kit.stepper1.onestep(direction=stepper.BACKWARD, style=stepper.SINGLE)
           self.kit.stepper2.onestep(direction=stepper.BACKWARD) #, style=stepper.SINGLE)
        # todo necessary to have both activated afterwards so paper can't move?

    def move_paper_left(self, amount_of_steps: int = 50):
        """

        @param amount_of_steps:
        @return:
        """
        self.total_roll += amount_of_steps
        self.kit.stepper2.release()
        for _ in range(amount_of_steps):
            self.kit.stepper1.onestep(direction=stepper.FORWARD, style=stepper.SINGLE)
            #self.kit.stepper2.onestep(direction=stepper.BACKWARD, style=stepper.SINGLE)
        # todo necessary to have both activated afterwards so paper can't move?
        #time.sleep(1.0)


    def roll_towards_next_sheet(self):
        """

        @return:
        """
        self.placement = PLACEMENT.NOT_FAR
        # # 1. first we move the paper a little bit
        # self.move_paper_left(amount_of_steps=20)
        # 1. the idea is that first we have to move from PLACEMENT.CORRECT towards PLACEMENT.NOT_FAR ( with a bool)
        # and onlya
        # then start listening again to PLACEMENT.CORRECT
        # 2. we go and check the position
        self.cc.start_vid_rec()

        paper_has_left_original_position = False
        paper_has_left_original_position_threshold = self.config.move_paper_threshold # amount of frames before deciding we really left the original position
        while True:
            # It's better to capture the still in this thread, not in the one driving the camera.
            self.cc.capture_during_rec()
            self.placement = self.sheet.qualify_position(str(self.config.temp_img.resolve()), self.sheet.template,
                                                         self.sheet.region_of_ok)
            print('placement : {}'.format(self.placement))
            if self.placement == PLACEMENT.CORRECT:
                print("found correct location")
                if paper_has_left_original_position:
                    break
                else:
                    #we need to get the paper first far enough to start measuring again
                    self.move_paper_left(amount_of_steps=5)
                    continue
            if self.placement == PLACEMENT.TOO_FAR:
                self.move_paper_right(amount_of_steps=5)
                continue
            if self.placement == PLACEMENT.NOT_FAR:
                if paper_has_left_original_position_threshold <=0:
                    paper_has_left_original_position = True
                paper_has_left_original_position_threshold -= 1
                self.move_paper_left(amount_of_steps=5)
                continue
        self.cc.stop_vid_rec()

    def insert_sshkeyboard(self):
        print("inserting ssh keyboard")
        listen_keyboard(on_press=self.on_press, until="space", debug=True)

    def on_press(self, key):
        try:
            print('alphanumeric key {0} pressed'.format(
                key))
            if key == "a":
                self.move_paper_left(50)
            if key == "d":
                self.move_paper_right(50)
            if key == "r":  # release
                self.kit.stepper1.release()
                self.kit.stepper2.release()
            if key == "t":
                self.roll_towards_next_sheet()
            # if key == "w":
            #     sc.disable_suction()
            if key == "o":
                print("paper is aligned correctly")
                self.placement = PLACEMENT.CORRECT
        except AttributeError:
            print('special key {0} pressed'.format(
                key))


if __name__ == '__main__':
    parser = argparse.ArgumentParser(
        prog='paper control',
        description="a script to move the paper and to check if it's positioned correctly",
        epilog="it's all about the toilet paper")
    parser.add_argument('-i', '--interactive',
                        action='store_true', help='interactive usage')  # on/off flag

    args = parser.parse_args()
    config = Config()
    stepperControl = StepperControl(config)

    # Collect events until released
    if args.interactive:
        stepperControl.insert_sshkeyboard()

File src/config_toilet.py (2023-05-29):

import math
import os
from dataclasses import dataclass
from pathlib import Path

import git
from dotenv import load_dotenv


def get_git_root(path):
    git_repo = git.Repo(path, search_parent_directories=True)
    git_root = git_repo.git.rev_parse("--show-toplevel")
    return git_root


@dataclass
class Config:
    location = "dmg"
    ROOT_DIR = Path(get_git_root(Path.cwd()))  # os.path.abspath(os.curdir)

    dotenv_path = Path(ROOT_DIR / ".env")
    load_dotenv(dotenv_path)
    # warning, make sure your key is the secret key, not anon key if row level policy is enabled.
    URL = os.environ.get("URL")
    KEY = os.environ.get("KEY")

    location_files = Path(ROOT_DIR / "location_files" / location)

    # config settings for path finding
    raw_data_path = Path(location_files / "raw.csv")
    clean_data_path = Path(location_files / "clean.csv")
    tree_path = Path(location_files / "tree.csv")
    list_cols = ['object_name', 'creator']
    stemmer_cols = ['title', 'description']
    amount_of_tissues = 100
    amount_of_imgs_to_find = math.floor(amount_of_tissues / 2)

    # config settings for image conversions & creations
    tree_img_path = Path(location_files / "orig_imgs")
    converted_img_path = Path(location_files / "converted_imgs")
    in_between_page_path = Path(location_files / "in_between")
    draw_contour: bool = True
    draw_hatch: bool = False
    hatch_size: int = 16
    contour_simplify: int = 3
    no_polylines: bool = True
    resize: bool = True
    resolution: int = 1024
    fixed_size: bool = True

    # toilet paper sheet settings
    sheet_width = 110  # [mm]
    sheet_height = 80  # [mm]
    font_size = 4
    max_title_fontsize = 10
    max_circle_fontsize = 10
    max_extra_fontsize = 10
    year_fontsize = 10
    offset_x_text = 25
    offset_x_title = 15
    angle_offset = 20
    radius = (sheet_width / 2 - offset_x_text) * 0.6
    title_text_width = 40
    circle_text_width = 2 * radius - 4
    extra_text_width = 30
    fontface = "AVHershey Simplex"
    #Path(ROOT_DIR / "imageConversion/in_between_paper/font" / "MecSoft_Font-1.ttf") #"AVHersheySimplexLight.ttf")
    max_lines_circle = 2
    

    # plot settings
    pen_pos_up = 18  # [0-100]
    pen_pos_down = 7  # [0-100]
    speed_pendown = 20  # [1-110]
    model = 4  # AxiDraw MiniKit
    reordering = 2  # optimize plot before plotting:  Full; Also allow path reversal

    paper_offset = (0.2, 0.3) #TODO (x,y) coordinates where the paper is approx positioned

    # physical connections
    suction_GPIO = 18  # BCM
    stepperi2c = 0x63


    # camera settings
    region_of_interest = (283, 6, 51, 451)
    prep_img = Path(location_files / "prep.jpg")
    template = Path(location_files / "template.jpg")
    temp_img = Path(location_files / "temp.jpg")
    location_threshold = 0.2
    move_paper_threshold = 5

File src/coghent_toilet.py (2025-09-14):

"""
Coghent toilet

we want a state machine calling the different blocks of code:
---PREPPING---
1. Waiting state:
    1. no toilet paper rol is present and is prepared
    2. or we've finished a toilet paper roll
    DEBUG: A **light** gives signal that we're in waiting state
    NEXT STATE: we wait for a switch to indicate that we're going to the next state
    ! 4 way switch: forward, backward, neutral, ready to start
2. we find the path in the database of the museum we are (via config file)
    NEXT STATE: once path is found,
    DEBUG ERROR: if not found ERROR LAMP Path
3. prepare toilet paper images:
    1. we download the images
    2. convert images to linedraw vectors in the correct size
    3. create in between pages
    4. place them altogether in folder
---PRINTING---
4. roll the toilet paper roll state:
    1. we start rolling the toilet paper (1 NEMA stepper motor with two GT2 pulleys and inbetween e.g. this belt: https://www.123-3d.nl/123-3D-GT2-timing-belt-6-mm-gesloten-848-mm-i2751-t3046.html)
        ! We keep track of the amount of rotations
    2. we rotate a little and then start checking the camera
    NEXT STATE: once position is correct
5. print the next prepared image
    NEXT STATE: if more images present => state 4 when image is finished
    NEXT STATE: if no more images present => state 6 when image is finished
6. roll back toilet paper state
    DEBUG: the waiting light is shown that we're ready
    We roll back the paper already a bit in approx of the amount of rotations already done
"""
import threading

import pandas as pd
from finite_state_machine import StateMachine, transition
import time
from config_toilet import Config
from src.dBPathFinder.findOverlap import find_tree
from src.dBPathFinder import link_supabase, get_sb_data
from src.imageConversion import convert_folder_to_linedraw, create_in_between_images, \
    download_images_from_tree
from src.physical_control.keypad_controller import KeypadController, Mode, Functions
from src.physical_control.paper_control import StepperControl
from src.print_timeline.print_timeline import TimelinePrinter
from src.print_timeline.plotter.plotter import move_to_start_offset

"""
#todo write documentation


"""


class ToiletPaperStateMachine(StateMachine):
    initial_state = "waiting"

    def __init__(self, config, key):
        self.config = config
        self.state = self.initial_state
        super().__init__()  # init only to be called after setting self.state
        self.df_tree = None
        self.stepperControl = StepperControl(config=config)
        self.timeline = TimelinePrinter(config=config)

        self.key = key
        self.key.set_message(0, "hello toilet printer fellow!")
        self.image_number = 0
        self.finished = False

    @transition(source="waiting", target="path_finding")
    def find_path(self):
        """

        we find a possible path for this run and generate the csvs for this
        """
        self.key.set_message(0, "searching a path")
        # 1. Make connection with supabase database
        sb = link_supabase(config)
        # 2. fetch the dataframe for current location
        input_df = get_sb_data(sb, config.location)
        # 3. find the tree path
        self.df_tree = find_tree(input_df=input_df,
                                 output_file=config.tree_path,
                                 stemmer_cols=config.stemmer_cols,
                                 list_cols=config.list_cols,
                                 amount_of_imgs_to_find=config.amount_of_imgs_to_find)

    @transition(source="waiting", target="test_df")
    def test_df(self):
        self.key.set_message(0, "testing a path")

        self.df_tree = pd.read_csv(config.tree_path, index_col=0)

    @transition(source=["path_finding", "test_df"], target="prep_imgs")
    def prep_imgs(self):
        """
        1. we download the images for this tree
        2. we create the in-between pages
        3. we convert the images to lineart
        """
        self.key.set_message(0, "prepping imgs")

        # 1.
        download_images_from_tree(df=self.df_tree,
                                  output_path=config.tree_img_path)
        print("images downloaded")
        # 2.
        create_in_between_images(df=self.df_tree, output_path=config.in_between_page_path, config=config)
        print("in beteen images created")
        # 3.
        convert_folder_to_linedraw(input_path=config.tree_img_path,
                                   output_path=config.converted_img_path,
                                   config=config)
        print("images converted to lineart")

    @transition(source=["prep_imgs", "waiting"], target="prep_timeline")
    def prep_timeline(self):
        self.key.set_message(0, "timeline")

        list1 = self.timeline.get_list_of_files(config.converted_img_path)
        list2 = self.timeline.get_list_of_files(config.in_between_page_path)
        self.timeline.create_comb_list(list1, list2)

    @transition(source=["prep_timeline"], target="move_to_start_pos")
    def move_to_start_pos(self):
        self.timeline.move_to_start_offset()
        self.key.set_message(0, "moving to start")

    @transition(source=["move_to_start_pos", "prep_timeline", "print_img"], target="roll_paper")
    def roll_paper(self):
        self.key.set_message(0, "roll it!")

        print("preparing sheet {} for {}".format(self.image_number, self.timeline.get_img(self.image_number)))
        # ! bijhouden hoeveel we afrollen
        self.stepperControl.roll_towards_next_sheet()

    @transition(source="roll_paper", target="print_img")
    def print_img(self):
        print("plotting image {}".format(self.image_number))
        self.key.set_messages("print it!", "img {}".format(self.image_number))
        # 1. move to start position
        # 
        # 2. start printing
        self.timeline.plot_img_from_list(self.image_number)
        # 3. update the image number if finished
        if self.image_number < self.config.amount_of_tissues:
            self.image_number += 1
        else:
            self.finished = True

    @transition(source="print_img", target="roll_back_paper")
    def roll_back(self):
        self.stepperControl.move_paper_right(self.stepperControl.total_roll)
        # todo check if we're not pulling too far?

    @transition(source="roll_back_paper", target="waiting")
    def wait(self):
        self.finished = False


def thread_keep_paper_rolling(direction, enabled, stop):
    while True:
        if stop.is_set():
            print("stopping paper rolling thread")
            stop.clear()
            break
        if enabled.is_set():
        #enabled.wait()
            if direction.is_set():
                stm.stepperControl.move_paper_right(50)
            else:
                stm.stepperControl.move_paper_left(50)
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

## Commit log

2022-09-11 initial flow for treebuilding
2022-09-18 threaded overlap finding with checking if img exists
2022-09-28 added tree viz functionality
    [DMG_tree.csv]
2022-09-28 adaptions for raspberry pi made
2022-10-02 removed functions used for non threaded approach and before first searching image links
2022-10-04 adapted for single branch pathfinding
    [DMG_tree.csv]
2022-11-23 updates of 3D files & start for image masking
    [StepperMotorBracket.stl, left.stl, right.stl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]
2022-11-23 updated stl files
    [left.stl, right.stl]
2022-11-30 added more 3D print files, initiated a supabase link and adapted preprocessing for this
    [air_vent_conn.stl, toilet_roll_balancer.stl]
2022-12-04 added lasercut files for enclosure v1
2022-12-10 added magnet test
    [nema17_toilet_fixation.stl, other_side_toilet_fixation.stl]
2023-01-07 updated stepper control, 3D files and template matching
    [nema17_toilet_fixation.stl, nema17_toilet_fixation_1.stl, nema17_toilet_fixation_2.stl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]
2023-01-07 updated stepper test
2023-01-15 test script for steppers updated
2023-01-28 updated state machine for test print
2023-01-29 set correct values for steppers
    [steppers_test.py]
2023-03-05 adaptions for making sure images have correct sizings
    [config_toilet.py, template_matching.py]
2023-03-09 bugfix closing camcontrol module when prepping
    [template_matching.py]
2023-03-16 push for computer crash
    [coghent_toilet.py, paper_control.py]
2023-03-23 updated lasercut files
2023-04-01 added fusion design
    [paper_printer v165.f3d]
2023-04-03 added v3 models
    [StepperMotorBracket.stl, air_vent_conn.stl, left.stl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]
2023-04-05 updated some documentation
    [light_bulb_fixation.stl]
2023-04-18 updated to v4
    [paper_printer v177.f3d]
2023-05-21 integration updates: max location value taken into camera account (template matching)
2023-05-24 added calibration svg
2023-05-29 small update for steppers
2023-05-29 thread approach
2023-05-29 rolling functions via thread
2023-05-29 working better for plotting, need to make thread
2023-05-29 thread restarting possible
2023-06-15 added new grabber side prints
    [v6.stl, v6_fix.stl]
2025-12-09 Remove Git LFS and convert files to regular Git objects
    [paper_printer v165.f3d, paper_printer v166.f3d, paper_printer v177.f3d]
